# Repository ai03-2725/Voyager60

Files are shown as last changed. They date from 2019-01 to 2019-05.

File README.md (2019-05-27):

# Voyager60
A versatile, modern 60% PCB

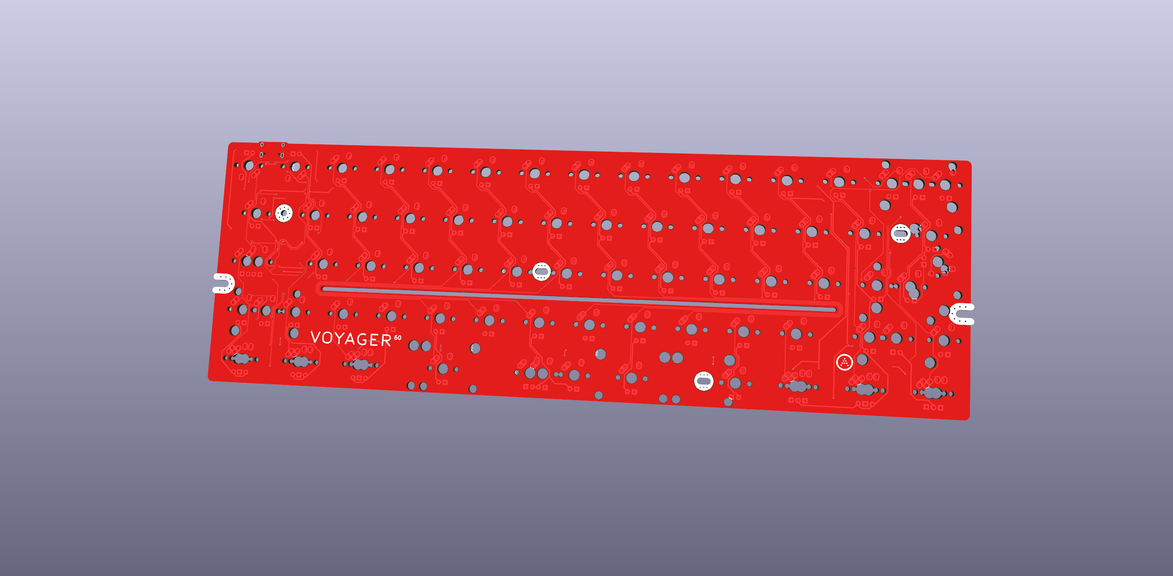
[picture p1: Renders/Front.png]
Render


#### In light of recent claims that I am 100% liable for any of my open source PCBs, I am adding this disclaimer.
#### I provide these PCBs as a reference for designing keyboard PCBs. Using them within your projects will require a will to do research of one's own and to learn the workings of them, potentially fixing issues if they exist.
# I provide these PCBs without liability and without any guarantees regarding functionality, as expressed in the MIT license under which all of these PCBs are licensed.

### Features
* In-switch LED backlighting
* RGB underglow
* Decent amount of layout compatibility - [View supported layouts](http://www.keyboard-layout-editor.com/#/gists/c13b7f096e4a905736771dd79d809fa2)
* Slot cutout for maximum flexibility and typing comfort
* Over-current and static discharge protection
* Fully open-source

### The Voyager PCB Family
The Voyager PCBs offer fully featured PCBs fit for any keyboard, whether mass production or high-end.

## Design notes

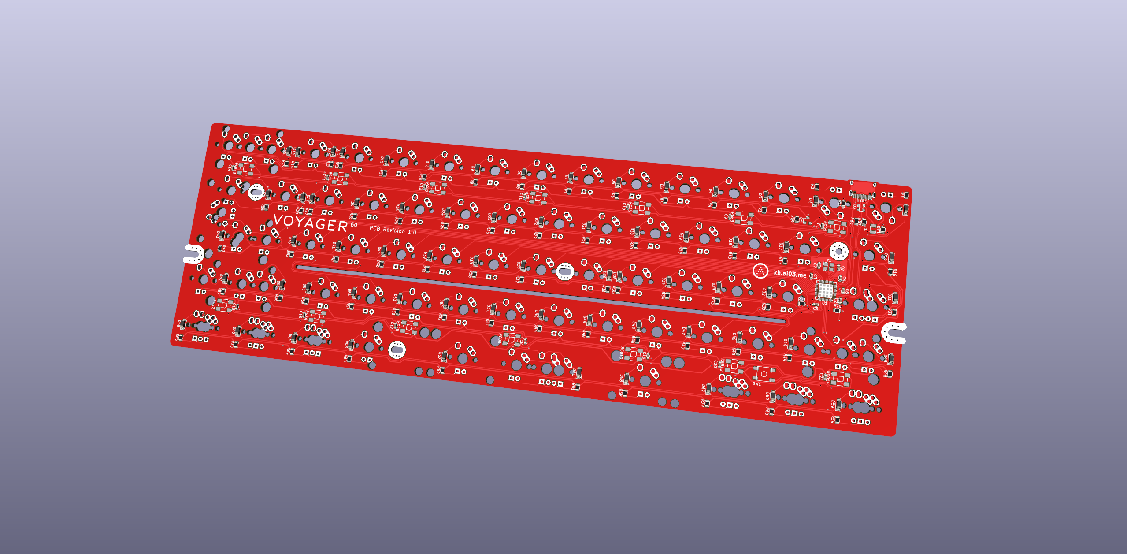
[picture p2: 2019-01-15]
Renders/Back.png

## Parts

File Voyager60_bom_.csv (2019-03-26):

Component | Description | Part | References | Value | Footprint | Quantity Per PCB | Datasheet
1 | Capacitor, Ceramic, 15V or more | C_Small | C1 C3 C4 C5 C9 C10 C11 C12 C13 C14 C15 C16 C17 C18 C19 C20 C21 | 0.1uF | C_0603 | 17
2 | Capacitor, Ceramic, 15V or more | C_Small | C2 | 10uF | C_0603 | 1
3 | Capacitor, Ceramic, 15V or more | C_Small | C6 | 1uF | C_0603 | 1
4 | Capacitor, Ceramic, 15V or more | C_Small | C7 C8 | 22pF | C_0603 | 2
5 | Diode, Generic | D_Small | D1 D2 D3 D4 D5 D6 D7 D8 D9 D10 D11 D12 D13 D14 D16 D17 D18 D19 D20 D21 D22 D23 D24 D25 D26 D27 D28 D29 D30 D31 D32 D33 D34 D35 D36 D37 D38 D39 D40 D41 D42 D43 D44 D45 D46 D47 D48 D49 D50 D51 D52 D53 D54 D55 D56 D57 D58 D59 D60 D61 D62 D63 D64 D65 D67 D68 | SOD-123 | D_SOD-123 | 66
6 | Polyfuse, 500mA hold, 1A trip | Polyfuse_Small | F1 | 500mA | Fuse_SMD1206_Reflow | 1
7 | N-Channel MOSFET | 2N7002 | Q1 | 2N7002 | SOT-23 | 1 | https://www.fairchildsemi.com/datasheets/2N/2N7002.pdf
8 | Resistor, Generic | R_Small | R70 | 10k | R_0805 | 1
9 | Resistor, Generic | R_Small | R1 R2 R3 R4 R5 R6 R7 R8 R9 R10 R11 R12 R13 R14 R16 R17 R18 R19 R20 R21 R22 R23 R24 R25 R26 R27 R28 R29 R30 R31 R32 R33 R34 R35 R36 R37 R38 R39 R40 R41 R42 R43 R44 R45 R46 R47 R48 R49 R50 R51 R52 R53 R54 R55 R56 R57 R58 R59 R60 R61 R62 R63 R64 R65 R69 R71 R72 R75 | 1k | R_0805 | 68
10 | Resistor, Generic | R_Small | R67 R68 | 22 | R_0805 | 2
11 | Resistor, Generic | R_Small | R73 R74 | 5.1k | R_0805 | 2
12 | WS2812B RGB LED, 5050 | WS2812B | RGB1 RGB2 RGB3 RGB4 RGB5 RGB6 RGB7 RGB8 RGB9 RGB10 RGB11 RGB12 RGB13 RGB14 | WS2812B | WS2812B | 14
13 | 5.2 x 5.2mm Push Button, SMT | SW_Push | SW1 | 5.2x5.2mm | SKQG-1155865 | 1
14 | ATmega32U4-MU | ATmega32U4-MU-MCU_Microchip_ATmega | U1 | ATmega32U4-MU | QFN-44-1EP_7x7mm_Pitch0.5mm | 1 | http://ww1.microchip.com/downloads/en/DeviceDoc/Atmel-7766-8-bit-AVR-ATmega16U4-32U4_Datasheet.pdf
15 | ESD Protection IC | PRTR5V0U2X | U2 | PRTR5V0U2X | SOT143B | 1
16 | USB Type-C Connector | HRO-TYPE-C-31-M-12 | USB1 | HRO-TYPE-C-31-M-12 | HRO-TYPE-C-31-M-12-Assembly | 1
17 | Crystal, 3.2 x 2.5mm, 16MHz | Crystal_GND24 | Y1 | 16Mhz | Crystal_SMD_3225-4pin_3.2x2.5mm | 1
Component Groups: | 17
Component Count: | 181
Fitted Components: | 181
Number of PCBs: | 1
Total components: | 181
Schematic Version:
Schematic Date:
BoM Date: | 3/26/2019 0:17
Schematic Source: | C:\Users\Ryota\Documents\GitHub\Voyager60\Voyager60.sch
KiCad Version: | Eeschema (5.0.2)-1

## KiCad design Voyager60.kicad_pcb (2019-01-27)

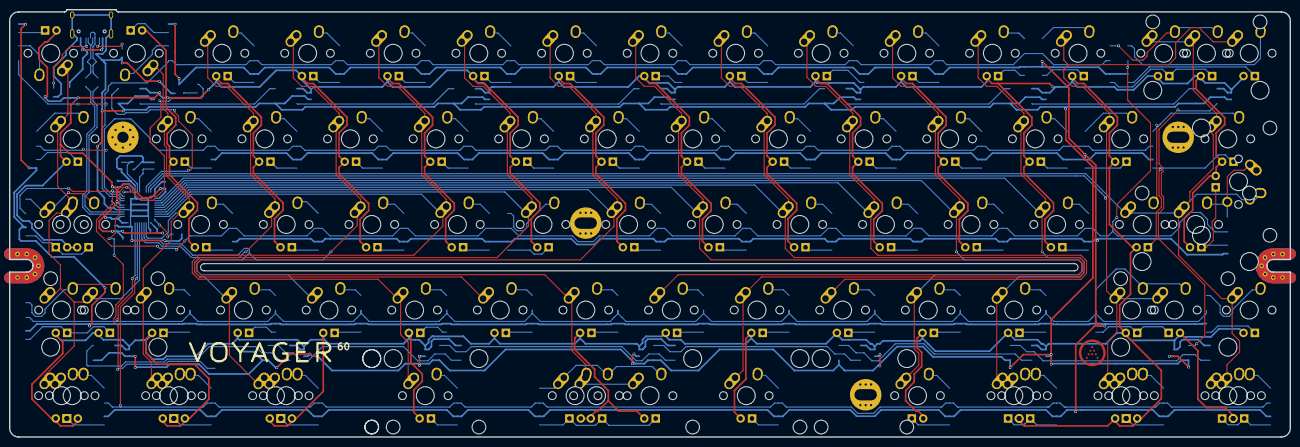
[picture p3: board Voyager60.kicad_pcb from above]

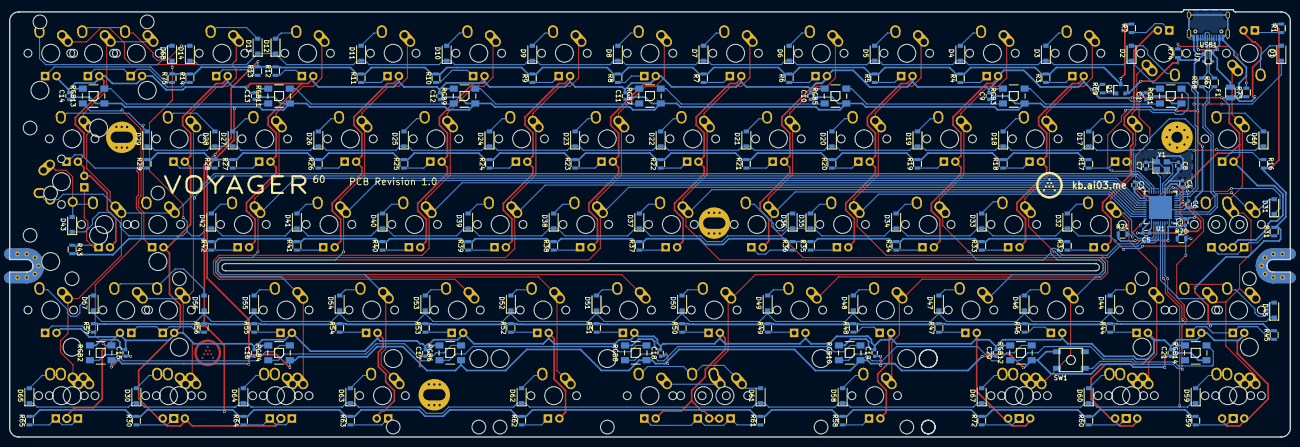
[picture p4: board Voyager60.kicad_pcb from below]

Board: 2 copper layers, 285.0 x 95.1 mm, 261 parts (181 on the bottom side), 182 nets.

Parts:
C1, C3, C4, C5, C9, C10, C11, C12, C13, C14, C15, C16, C17, C18, C19, C20, C21: 0.1uF; C_0603
C2: 10uF; C_0603
C6: 1uF; C_0603
C7, C8: 22pF; C_0603
D1, D2, D3, D4, D5, D6, D7, D8, D9, D10, D11, D12, D13, D14, D16, D17, D18, D19, D20, D21, D22, D23, D24, D25, D26, D27, D28, D29, D30, D31, D32, D33, D34, D35, D36, D37, D38, D39, D40, D41, D42, D43, D44, D45, D46, D47, D48, D49, D50, D51, D52, D53, D54, D55, D56, D57, D58, D59, D60, D61, D62, D63, D64, D65, D67, D68: SOD-123; D_SOD-123
F1: 500mA; Fuse_SMD1206_Reflow
K_#1, K_#2, K_#3, K_#4, K_#5, K_#6, K_#7, K_#8, K_#9, K_#10: MX-1U
K_'1: MX-1U
K_,1: MX-1U
K_-1: MX-1U
K_.1: MX-1U
K_/1: MX-1U
K_;1: MX-1U
K_=1: MX-1U
K_A1: MX-1U
K_ALT1: MX-1.25U
K_ALT2: MX-1.5U; MX-1.5U-FLIPPED
K_B1: MX-1U
K_BACK1: MX-2U
K_C1: MX-1U
K_CAPS1: MX-1.75U
K_CAPS2: MX-1.25U; MX-1.25U-FLIPPED
K_CTRL1: MX-1.25U
K_CTRL2: MX-1.5U; MX-1.5U-FLIPPED
K_D1: MX-1U
K_E1: MX-1U
K_ENTER1: MX-2.25U
K_ENTER2: MX-ISO; MX-ISO-ReversedStabilizers
K_ESC1: MX-1U
K_F1: MX-1U
K_G1: MX-1U
K_H1: MX-1U
K_I1: MX-1U
K_J1: MX-1U
K_K1: MX-1U
K_L1: MX-1U
K_M1: MX-1U
K_N1: MX-1U
K_O1: MX-1U
K_P1: MX-1U
K_Q1: MX-1U
K_R1: MX-1U
K_RALT2: MX-1.25U; MX-1.25U-FLIPPED
K_RALT3: MX-1.5U; MX-1.5U-FLIPPED
K_RCTRL2: MX-1.25U
K_RCTRL3: MX-1.5U; MX-1.5U-FLIPPED
K_RMENU2: MX-1.25U; MX-1.25U-FLIPPED
K_RSHIFT1: MX-2.75U; MX-2.75U-FLIPPED
K_RWIN2: MX-1.25U
K_RWIN3: MX-1U
K_S1: MX-1U
K_SBACK1, K_SBACK2: MX-1U
K_SHIFT1: MX-2.25U
K_SHIFT2: MX-1.25U
K_SHIFT3: MX-1U
K_SPACE1: MX-7U; MX-7U-ReversedStabilizers
K_SPACE2: MX-6.25U; MX-6.25U-ReversedStabilizers
K_SPACE3: MX-2.25U; MX-2.25U-ReversedStabilizers
K_SPACE4: MX-2.75U; MX-2.75U-ReversedStabilizers
K_SPACE5: MX-1.25U; MX-1.25U-FLIPPED
K_SRSHIFT1: MX-1.75U
K_SRSHIFT2: MX-1U
K_T1: MX-1U
K_TAB1: MX-1.5U
K_U1: MX-1U
K_V1: MX-1U
K_W1: MX-1U
K_WIN1: MX-1.25U
K_WIN2: MX-1U; MX-1U-FLIPPED
K_X1: MX-1U
K_Y1: MX-1U
K_Z1: MX-1U
K_[1: MX-1U
K_\1: MX-1.5U
K_\2: MX-1U
K_]1: MX-1U
Q1: 2N7002; SOT-23
R1, R2, R3, R4, R5, R6, R7, R8, R9, R10, R11, R12, R13, R14, R16, R17, R18, R19, R20, R21, R22, R23, R24, R25, R26, R27, R28, R29, R30, R31, R32, R33, R34, R35, R36, R37, R38, R39, R40, R41, R42, R43, R44, R45, R46, R47, R48, R49, R50, R51, R52, R53, R54, R55, R56, R57, R58, R59, R60, R61, R62, R63, R64, R65, R69, R71, R72, R75: 1k; R_0805
R67, R68: 22; R_0805
R70: 10k; R_0805
R73, R74: 5.1k; R_0805
RGB1, RGB2, RGB3, RGB4, RGB5, RGB6, RGB7, RGB8, RGB9, RGB10, RGB11, RGB12, RGB13, RGB14: WS2812B
SW1: 5.2x5.2mm; SKQG-1155865
U1: ATmega32U4-MU; QFN-44-1EP_7x7mm_Pitch0.5mm
U2: PRTR5V0U2X; SOT143B
USB1: HRO-TYPE-C-31-M-12; HRO-TYPE-C-31-M-12-Assembly
Y1: 16Mhz; Crystal_SMD_3225-4pin_3.2x2.5mm

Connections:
+5V: C1.2, C2.2, C3.2, C4.2, C5.2, C9.2, C10.2, C11.2, C12.2, C13.2, C14.2, C15.2, C16.2, C17.2, C18.2, C19.2, C20.2, C21.2, F1.1, K_#1.3, K_#2.3, K_#3.3, K_#4.3, K_#5.3, K_#6.3, K_#7.3, K_#8.3, K_#9.3, K_#10.3, K_'1.3, K_,1.3, K_-1.3, K_.1.3, K_/1.3, K_;1.3, K_=1.3, K_A1.3, K_ALT1.3, K_ALT2.3, K_B1.3, K_BACK1.3, K_C1.3, K_CAPS1.3, K_CAPS2.3, K_CTRL1.3, K_CTRL2.3, K_D1.3, K_E1.3, K_ENTER1.3, K_ENTER2.3, K_ESC1.3, K_F1.3, K_G1.3, K_H1.3, K_I1.3, K_J1.3, K_K1.3, K_L1.3, K_M1.3, K_N1.3, K_O1.3, K_P1.3, K_Q1.3, K_R1.3, K_RALT2.3, K_RALT3.3, K_RCTRL2.3, K_RCTRL3.3, K_RMENU2.3, K_RSHIFT1.3, K_RWIN2.3, K_RWIN3.3, K_S1.3, K_SBACK1.3, K_SBACK2.3, K_SHIFT1.3, K_SHIFT2.3, K_SHIFT3.3, K_SPACE1.3, K_SPACE2.3, K_SPACE3.3, K_SPACE4.3, K_SPACE5.3, K_SRSHIFT1.3, K_SRSHIFT2.3, K_T1.3, K_TAB1.3, K_U1.3, K_V1.3, K_W1.3, K_WIN1.3, K_WIN2.3, K_X1.3, K_Y1.3, K_Z1.3, K_[1.3, K_\1.3, K_\2.3, K_]1.3, R70.1, RGB1.1, RGB2.1, RGB3.1, RGB4.1, RGB5.1, RGB6.1, RGB7.1, RGB8.1, RGB9.1, RGB10.1, RGB11.1, RGB12.1, RGB13.1, RGB14.1, U1.2, U1.7, U1.14, U1.24, U1.34, U1.44
COL0: K_CAPS1.1, K_CAPS2.2, K_CTRL1.1, K_CTRL2.1, K_ESC1.1, K_SHIFT1.1, K_SHIFT2.1, K_TAB1.1, U1.39
COL1: K_#1.1, K_A1.1, K_Q1.1, K_SHIFT3.1, K_WIN1.1, K_WIN2.1, U1.36
COL2: K_#2.1, K_ALT1.1, K_ALT2.1, K_S1.1, K_W1.1, K_Z1.1, U1.38
COL3: K_#3.1, K_D1.1, K_E1.1, K_X1.1, U1.37
COL4: K_#4.1, K_C1.1, K_F1.1, K_R1.1, K_SPACE3.1, U1.32
COL5: K_#5.1, K_G1.1, K_T1.1, K_V1.1, U1.31
COL6: K_#6.1, K_B1.1, K_H1.1, K_SPACE1.1, K_SPACE2.1, K_SPACE5.2, K_Y1.1, U1.30
COL7: K_#7.1, K_J1.1, K_N1.1, K_U1.1, U1.29
COL8: K_#8.1, K_I1.1, K_K1.1, K_M1.1, K_SPACE4.1, U1.28
COL9: K_#9.1, K_,1.1, K_L1.1, K_O1.1, U1.27
COL10: K_#10.1, K_.1.1, K_;1.1, K_P1.1, K_RALT2.1, U1.26
COL11: K_'1.1, K_-1.1, K_/1.1, K_RALT3.1, K_RWIN2.1, K_[1.1, U1.25
COL12: K_=1.1, K_RMENU2.1, K_RSHIFT1.1, K_RWIN3.1, K_SBACK2.1, K_SRSHIFT1.1, K_]1.1, U1.22
COL13: K_BACK1.1, K_ENTER1.1, K_ENTER2.1, K_RCTRL2.1, K_RCTRL3.1, K_SBACK1.1, K_SRSHIFT2.1, K_\1.1, K_\2.1, U1.21
D+: R68.1, U1.4
D-: R67.1, U1.3
GND: C1.1, C2.1, C3.1, C4.1, C5.1, C6.2, C7.2, C8.2, C9.1, C10.1, C11.1, C12.1, C13.1, C14.1, C15.1, C16.1, C17.1, C18.1, C19.1, C20.1, C21.1, Q1.2, R71.1, R73.1, R74.1, RGB1.3, RGB2.3, RGB3.3, RGB4.3, RGB5.3, RGB6.3, RGB7.3, RGB8.3, RGB9.3, RGB10.3, RGB11.3, RGB12.3, RGB13.3, RGB14.3, SW1.1, U1.5, U1.15, U1.23, U1.35, U1.43, U1.45, U2.1, USB1.1, USB1.12, USB1.13, Y1.2, Y1.4
LEDGND: Q1.3, R1.2, R2.2, R3.2, R4.2, R5.2, R6.2, R7.2, R8.2, R9.2, R10.2, R11.2, R12.2, R13.2, R14.2, R16.2, R17.2, R18.2, R19.2, R20.2, R21.2, R22.2, R23.2, R24.2, R25.2, R26.2, R27.2, R28.2, R29.2, R30.2, R31.2, R32.2, R33.2, R34.2, R35.2, R36.2, R37.2, R38.2, R39.2, R40.2, R41.2, R42.2, R43.2, R44.2, R45.2, R46.2, R47.2, R48.2, R49.2, R50.2, R51.2, R52.2, R53.2, R54.2, R55.2, R56.2, R57.2, R58.2, R59.2, R60.2, R61.2, R62.2, R63.2, R64.2, R65.2, R72.2, R75.2
unnamed: C6.1, U1.6
unnamed: C7.1, U1.17, Y1.1
unnamed: C8.1, U1.16, Y1.3
unnamed: D1.2, K_ESC1.2
unnamed: D2.2, K_#1.2
unnamed: D3.2, K_#2.2
unnamed: D4.2, K_#3.2
unnamed: D5.2, K_#4.2
unnamed: D6.2, K_#5.2
unnamed: D7.2, K_#6.2
unnamed: D8.2, K_#7.2
unnamed: D9.2, K_#8.2
unnamed: D10.2, K_#9.2
unnamed: D11.2, K_#10.2
unnamed: D12.2, K_-1.2
unnamed: D13.2, K_=1.2
unnamed: D14.2, K_BACK1.2, K_SBACK1.2
unnamed: D16.2, K_TAB1.2
unnamed: D17.2, K_Q1.2
unnamed: D18.2, K_W1.2
unnamed: D19.2, K_E1.2
unnamed: D20.2, K_R1.2
unnamed: D21.2, K_T1.2
unnamed: D22.2, K_Y1.2
unnamed: D23.2, K_U1.2
unnamed: D24.2, K_I1.2
unnamed: D25.2, K_O1.2
unnamed: D26.2, K_P1.2
unnamed: D27.2, K_[1.2
unnamed: D28.2, K_]1.2
unnamed: D29.2, K_\1.2, K_\2.2
unnamed: D30.2, K_RMENU2.2, K_RWIN3.2
unnamed: D31.2, K_CAPS1.2, K_CAPS2.1
unnamed: D32.2, K_A1.2
unnamed: D33.2, K_S1.2
unnamed: D34.2, K_D1.2
unnamed: D35.2, K_F1.2
unnamed: D36.2, K_G1.2
unnamed: D37.2, K_H1.2
unnamed: D38.2, K_J1.2
unnamed: D39.2, K_K1.2
unnamed: D40.2, K_L1.2
unnamed: D41.2, K_;1.2
unnamed: D42.2, K_'1.2
unnamed: D43.2, K_ENTER1.2, K_ENTER2.2
unnamed: D44.2, K_SHIFT3.2
unnamed: D45.2, K_SHIFT1.2, K_SHIFT2.2
unnamed: D46.2, K_Z1.2
unnamed: D47.2, K_X1.2
unnamed: D48.2, K_C1.2
unnamed: D49.2, K_V1.2
unnamed: D50.2, K_B1.2
unnamed: D51.2, K_N1.2
unnamed: D52.2, K_M1.2
unnamed: D53.2, K_,1.2
unnamed: D54.2, K_.1.2
unnamed: D55.2, K_/1.2
unnamed: D56.2, K_RSHIFT1.2, K_SRSHIFT1.2
unnamed: D57.2, K_SRSHIFT2.2
unnamed: D58.2, K_SPACE3.2
unnamed: D59.2, K_CTRL1.2, K_CTRL2.2
unnamed: D60.2, K_WIN1.2, K_WIN2.2
unnamed: D61.2, K_SPACE1.2, K_SPACE2.2, K_SPACE5.1
unnamed: D62.2, K_SPACE4.2
unnamed: D63.2, K_RALT2.2
unnamed: D64.2, K_RALT3.2, K_RWIN2.2
unnamed: D65.2, K_RCTRL2.2, K_RCTRL3.2
unnamed: D67.2, K_ALT1.2, K_ALT2.2
unnamed: D68.2, K_SBACK2.2
unnamed: K_#1.4, R2.1
unnamed: K_#2.4, R3.1
unnamed: K_#3.4, R4.1
unnamed: K_#4.4, R5.1
unnamed: K_#5.4, R6.1
unnamed: K_#6.4, R7.1
unnamed: K_#7.4, R8.1
unnamed: K_#8.4, R9.1
unnamed: K_#9.4, R10.1
unnamed: K_#10.4, R11.1
unnamed: K_'1.4, R42.1
unnamed: K_,1.4, R53.1
unnamed: K_-1.4, R12.1
unnamed: K_.1.4, R54.1
unnamed: K_/1.4, R55.1
unnamed: K_;1.4, R41.1
unnamed: K_=1.4, R13.1
unnamed: K_A1.4, R32.1
unnamed: K_ALT1.4, K_ALT2.4, R72.1
unnamed: K_B1.4, R50.1
unnamed: K_BACK1.4, K_SBACK1.4, R14.1
unnamed: K_C1.4, R48.1
unnamed: K_CAPS1.4, K_CAPS2.4, R31.1
unnamed: K_CTRL1.4, K_CTRL2.4, R59.1
unnamed: K_D1.4, R34.1
unnamed: K_E1.4, R19.1
unnamed: K_ENTER1.4, K_ENTER2.4, R43.1
unnamed: K_ESC1.4, R1.1
unnamed: K_F1.4, R35.1
unnamed: K_G1.4, R36.1
unnamed: K_H1.4, R37.1
unnamed: K_I1.4, R24.1
unnamed: K_J1.4, R38.1
unnamed: K_K1.4, R39.1
unnamed: K_L1.4, R40.1
unnamed: K_M1.4, R52.1
unnamed: K_N1.4, R51.1
unnamed: K_O1.4, R25.1
unnamed: K_P1.4, R26.1
unnamed: K_Q1.4, R17.1
unnamed: K_R1.4, R20.1
unnamed: K_RALT2.4, R63.1
unnamed: K_RALT3.4, K_RWIN2.4, R64.1
unnamed: K_RCTRL2.4, K_RCTRL3.4, R65.1
unnamed: K_RMENU2.4, K_RWIN3.4, R30.1
unnamed: K_RSHIFT1.4, K_SRSHIFT1.4, R56.1
unnamed: K_S1.4, R33.1
unnamed: K_SBACK2.4, R75.1
unnamed: K_SHIFT1.4, K_SHIFT2.4, R45.1
unnamed: K_SHIFT3.4, R44.1
unnamed: K_SPACE1.4, K_SPACE2.4, K_SPACE5.4, R61.1
unnamed: K_SPACE3.4, R58.1
unnamed: K_SPACE4.4, R62.1
unnamed: K_SRSHIFT2.4, R57.1
unnamed: K_T1.4, R21.1
unnamed: K_TAB1.4, R16.1
unnamed: K_U1.4, R23.1
unnamed: K_V1.4, R49.1
unnamed: K_W1.4, R18.1
unnamed: K_WIN1.4, K_WIN2.4, R60.1
unnamed: K_X1.4, R47.1
unnamed: K_Y1.4, R22.1
unnamed: K_Z1.4, R46.1
unnamed: K_[1.4, R27.1
unnamed: K_\1.4, K_\2.4, R29.1
unnamed: K_]1.4, R28.1
unnamed: Q1.1, R69.1
unnamed: R67.2, U2.3, USB1.5, USB1.7
unnamed: R68.2, U2.2, USB1.6, USB1.8
unnamed: R69.2, U1.12
unnamed: R70.2, SW1.2, U1.13
unnamed: R71.2, U1.33
unnamed: R73.2, USB1.4
unnamed: R74.2, USB1.10
unnamed: RGB1.2, RGB3.4
unnamed: RGB2.2, RGB4.4
unnamed: RGB3.2, RGB5.4
unnamed: RGB4.2, RGB6.4
unnamed: RGB5.2, RGB7.4
unnamed: RGB6.2, RGB8.4
unnamed: RGB7.2, RGB9.4
unnamed: RGB10.2, RGB12.4
unnamed: RGB8.2, RGB10.4
unnamed: RGB11.2, RGB13.4
unnamed: RGB9.2, RGB11.4
unnamed: RGB12.2, RGB14.4
unnamed: RGB2.4, RGB13.2
RGBLED: RGB1.4, U1.20
ROW0: D1.1, D2.1, D3.1, D4.1, D5.1, D6.1, D7.1, D8.1, D9.1, D10.1, D11.1, D12.1, D13.1, D14.1, U1.9
ROW1: D16.1, D17.1, D18.1, D19.1, D20.1, D21.1, D22.1, D23.1, D24.1, D25.1, D26.1, D27.1, D28.1, D29.1, U1.10
ROW2: D31.1, D32.1, D33.1, D34.1, D35.1, D36.1, D37.1, D38.1, D39.1, D40.1, D41.1, D42.1, D43.1, D68.1, U1.11
ROW3: D44.1, D45.1, D46.1, D47.1, D48.1, D49.1, D50.1, D51.1, D52.1, D53.1, D54.1, D55.1, D56.1, D57.1, U1.41
ROW4: D30.1, D58.1, D59.1, D60.1, D61.1, D62.1, D63.1, D64.1, D65.1, D67.1, U1.40
VCC: F1.2, U2.4, USB1.2, USB1.11

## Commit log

2018-12-25 Begin progress
    [Voyager60-2018-12-25-18-22-20.sch, Voyager60.kicad_pcb, Voyager60.sch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]
2019-01-04 Place components
    [Voyager60.kicad_pcb, Voyager60.sch]
2019-01-07 Continue routing
    [Voyager60.kicad_pcb, Voyager60.sch]
2019-01-15 Finish routing
    [Voyager60.kicad_pcb]
2019-01-15 Route RGBs
    [Voyager60.kicad_pcb, Voyager60.sch]
2019-01-15 Finish routing, add decorations
    [Voyager60.kicad_pcb]
2019-01-15 Generate production data
    [Voyager60-B.Cu.gbl, Voyager60-B.Fab.gbr, Voyager60-B.Mask.gbs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]
2019-01-27 Update logo to universal spec
    [Voyager60-B.Cu.gbl, Voyager60-B.Fab.gbr, Voyager60-B.Mask.gbs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]
2019-03-26 Update bom
    [Voyager60.sch, Voyager60_bom_.csv]
